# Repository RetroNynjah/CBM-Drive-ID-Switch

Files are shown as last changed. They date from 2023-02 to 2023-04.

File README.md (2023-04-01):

# CBM Drive ID Switch
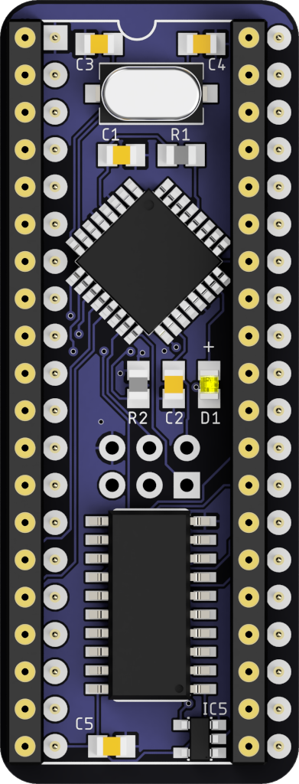
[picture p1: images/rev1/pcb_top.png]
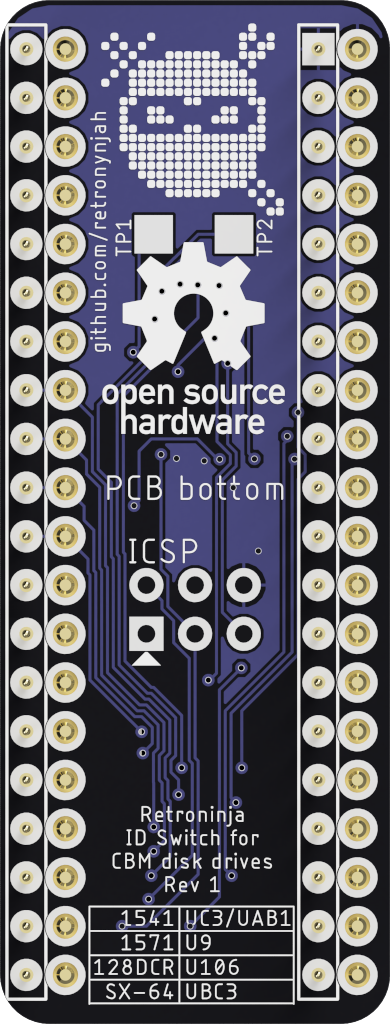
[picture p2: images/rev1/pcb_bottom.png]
   

This is a software controlled device ID switch for Commodore disk drives. It can be installed in any Commodore IEC disk drive but it only makes sense to install it in the drives that lack external DIP switches for ID selection but handy for the 1541 drive and for computers with built-in disk drives such as SX-64, C128D and C128DCR. 

## How it works
There's a microcontroller on the PCB that listens for strings of text on the drive data bus. Once a predefined string of bytes arrives on the bus, it flips the drive ID select pins on the VIA and resets the drive. 
The command that the drive listens for is x@RNDRVID where x is a number representing the drive ID to switch to.
Valid device numbers are 8, 9, 10, 11. In the switch command, these are specified as 8, 9, 0, 1. I.e. 0@RNDRVID is the command for switching to device #10. See the usage section for more information on the command.

## Installation

The installation is quite simple if the VIA chips are socketed. Just remove the correct VIA chip (MOS 6522) indicated in the table below, then install the switch in the socket and install the VIA chip in the switch. There is a notch printed on the top of the switch. This notch should be aligned with the notch on the socket.  
If the VIA is soldered to the PCB you will need to first desolder the VIA and install a socket (unless you want to solder the switch to the PCB which I wouldn't recommend). If you need to remove the VIA chip from the switch, be careful with the compoments on top of the PCB. Don't use any sharp objects to pry the chip out of the headers.

|Model			| VIA			| 
|:---:	|:---:	|
|1541			| UC3 or UAB1	|
|1571 (in 128D) | U9		  	|
|128DCR			| U106			|
|SX-64			| UBC3			|

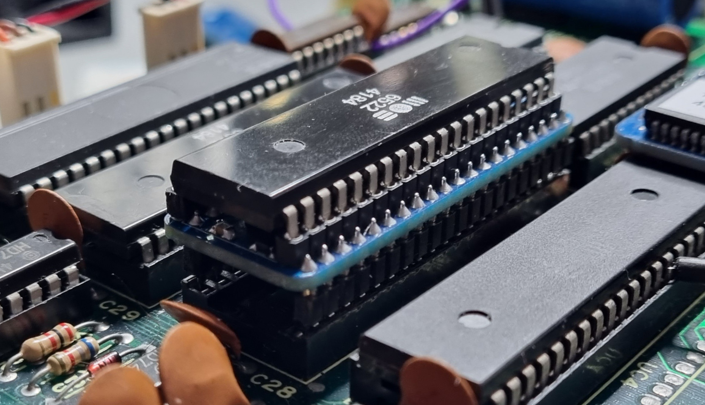
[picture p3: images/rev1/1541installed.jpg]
Switch installed in a CBM 1541

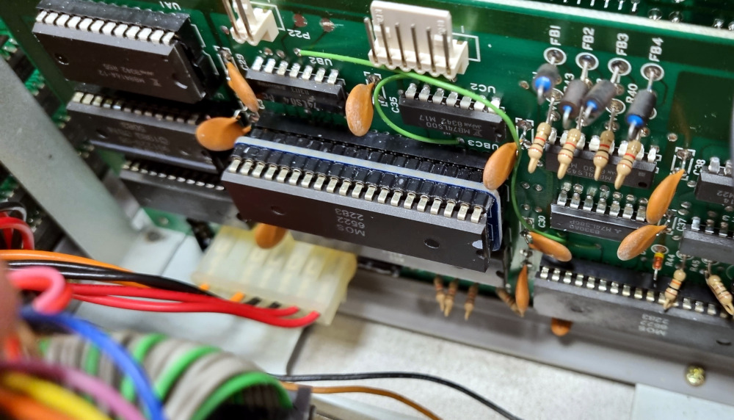
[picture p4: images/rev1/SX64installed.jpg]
Switch installed in an SX-64


## Usage

The device ID can be switched from basic using regular CBM DOS commands or by using DOS wedge commands from JiffyDOS or similar. 
Once the ID has been switched, the ID is saved and the drive will startup with the new ID until the ID is changed again. Resetting or power cycling the drive doesn't affect the saved ID.

In the below examples we switch ID of device #8 to device #9. 

#### From CBM DOS

The easiest command to use to get bytes on the drive bus is the LOAD command but other disk commands can be used too.  
```LOAD "9@RNDRVID",8```  
This generates a file not found error (unless you have a file named 9@RNDRVID ;) ). This error is to be expected and nothing to worry about.  

#### From JiffyDOS
```@"9@RNDRVID",8```  
or activate the drive first using CTRL+D or using @8 and use this command:  
```@9@RNDRVID```

## BOM

|Qty|Identifier |Part						|Comments							|
|---|----------	|---------------------------|-----------------------------------|
| 1 |IC2        |ATmega48A (TQFP32)			|Or compatible						|
| 1 |IC4        |SN74AHCT273NSR (SO20)     	|									|
| 1 |IC5        |SN74AHCT1G04DBVR (SOT23-5)	|									|
| 3 |C1,C2,C5   |100nF 0805    				|Ceramic capacitor					|
| 2 |C3,C4      |30pF 0805					|Ceramic capacitor					|
| 1 |R1         |10kΩ 0805					|									|
| 1 |Y1         |ECS-200-20-3X-TR			|Crystal 20MHz						|
| 2 |			|Female header row 			|20pin 2.54mm (for VIA chip)        |
| 2 |			|Male header row			|20pin 2.54mm (round or flat pins)	|
| 1 |D1			|LED 0805					|Optional							|
| 1 |R2			|560Ω 0805					|Optional							|

You can use any larger pin-compatible ATmega MCU such as ATmega88 or ATmega328.  
All variants seem to work including the not 100% pin-compatible PB version.  
The test points TP1 and TP2 are connected to ATmega pins PC1 and PC2 (Arduino pins A1 and A2) and can possibly be used for debugging or for some external connections.  
The optional LED (D1) and its resistor can also be used for debugging purposes but are difficult to see when VIA is installed so the may as well be left out. 

Installaion in the plastic version of C128D with the 1571 controller board covered by an RF shield requires a low profile switch. Flat stackable headers (Arduino shield headers) soldered from the top side is recommended in this case.  
<img src="images/stackableheader.jpg" alt="Stackable type header" width="400"/>  
Place a socket under the PCB and insert the stackable header pins through the PCB and solder them in place from the top side. The PCB can be removed from socket after soldering a pin on each end. The angle of the pins can then be adjusted before soldering the rest of the pins.
<img src="images/stackableheader2.jpg" alt="Stackable header inserted for soldering" width="600"/>  
When done, cut off the header part so that only the bottom part of the pins are left.  
I haven't found any 20-pin stackable headers but two 10-pin headers on each side works fine.  

Round machined headers add a few millimeters to the height but is fine in C128DCR, SX-64 and 1541 which all have more headroom.  

<img src="images/rev1/build.jpg" alt="Completed switch" width="600"/>

## Parallel version
I also made a version with a header for a parallel cable since parallel connections can be made using the same VIA.  
<img src="images/rev1/par_pcb_top.png" alt="PCB rendering" width="300"/> <img src="images/rev1/par_pcb_bottom.png" alt="PCB rendering" width="300"/>  

It can be used with SpeedDos ROM+Kernal and a userport adapter such as the one designed by Sven Petersen:  
https://github.com/svenpetersen1965/1541-parallel-adapter-SpeedDOS
The header on the Drive ID Switch has the same pinout as the one on Sven Petersen's 1541 adapter.  
With the proper cable, the parallel interface can also be used for nibble transfers with a Zoomfloppy or similar interface.  

<img src="images/rev1/1541parinstalled.jpg" alt="Switch installed in an SX-64" width="600"/>  

The pin-out of the parallel connector is connected to VIA pins according to the below table.

|Header pin |VIA pin    |
|-----------|-----------|
|1          |CA2 (39)   |
|2          |PA0 (2)    |
|3          |PA1 (3)    |
|4          |PA2 (4)    |
|5          |PA3 (5)    |
|6          |PA4 (6)    |
|7          |PA5 (7)    |
|8          |PA6 (8)    |
|9          |PA7 (9)    |
|10         |CB1 (18)   |

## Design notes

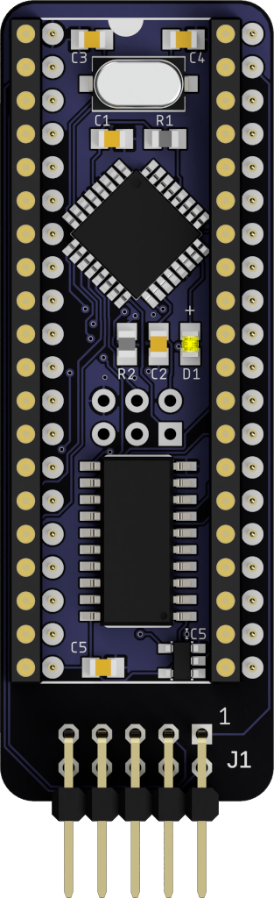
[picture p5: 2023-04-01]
images/rev1/par_pcb_top.png

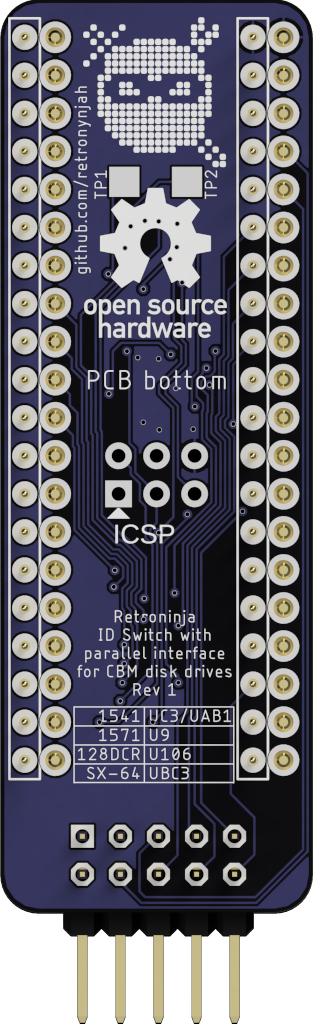
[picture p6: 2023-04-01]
images/rev1/par_pcb_bottom.png

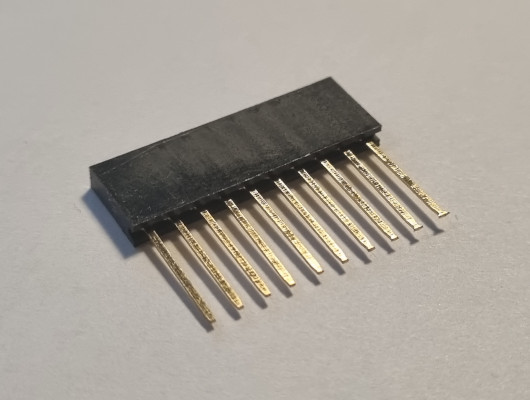
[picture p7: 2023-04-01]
images/stackableheader.jpg

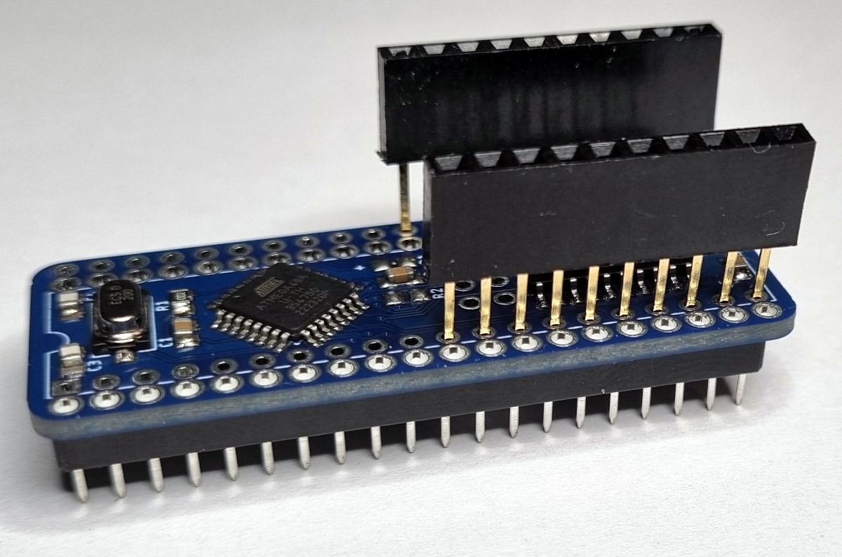
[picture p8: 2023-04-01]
images/stackableheader2.jpg

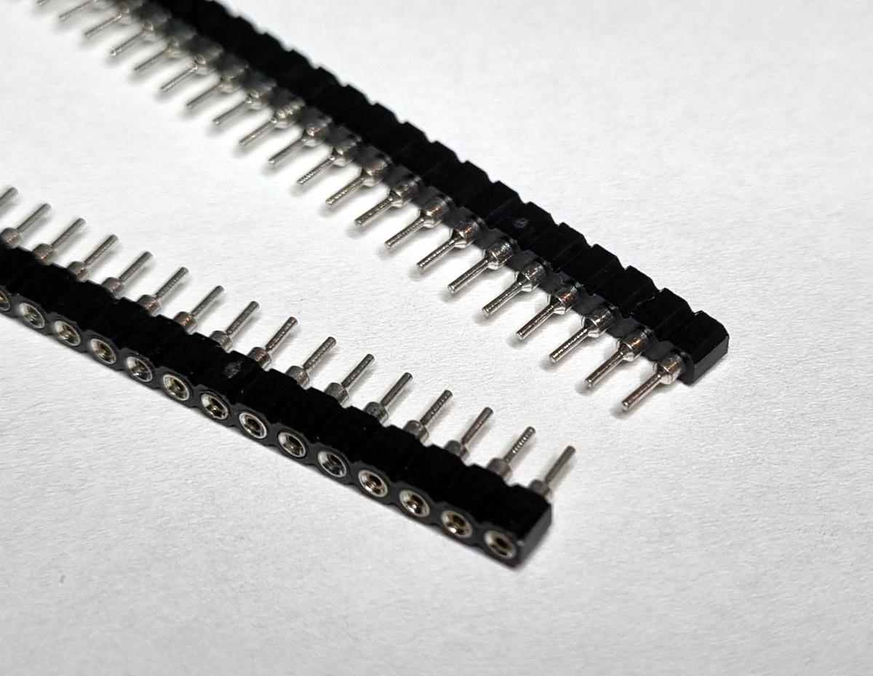
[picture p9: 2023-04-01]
images/femaleheader.jpg

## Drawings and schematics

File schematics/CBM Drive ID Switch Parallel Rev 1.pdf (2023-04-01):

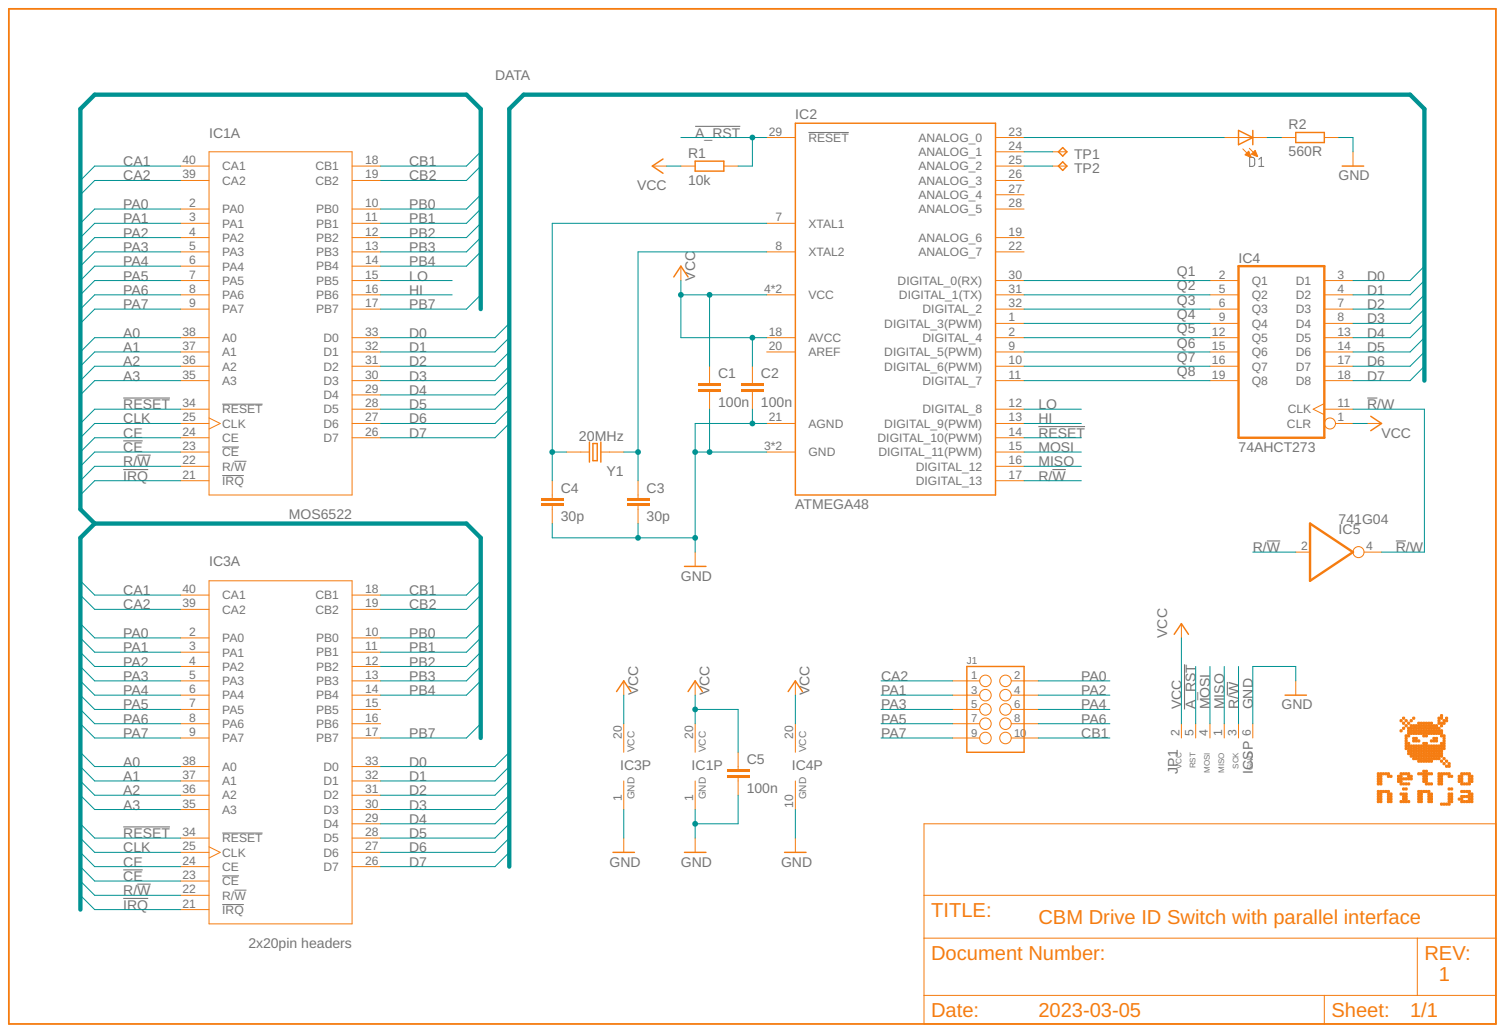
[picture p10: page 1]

SCK RST VCC MOSI GND

CBM Drive ID Switch with parallel interface

Document Number: | REV: 1

Date: 2023-03-05 | Sheet: 1/1

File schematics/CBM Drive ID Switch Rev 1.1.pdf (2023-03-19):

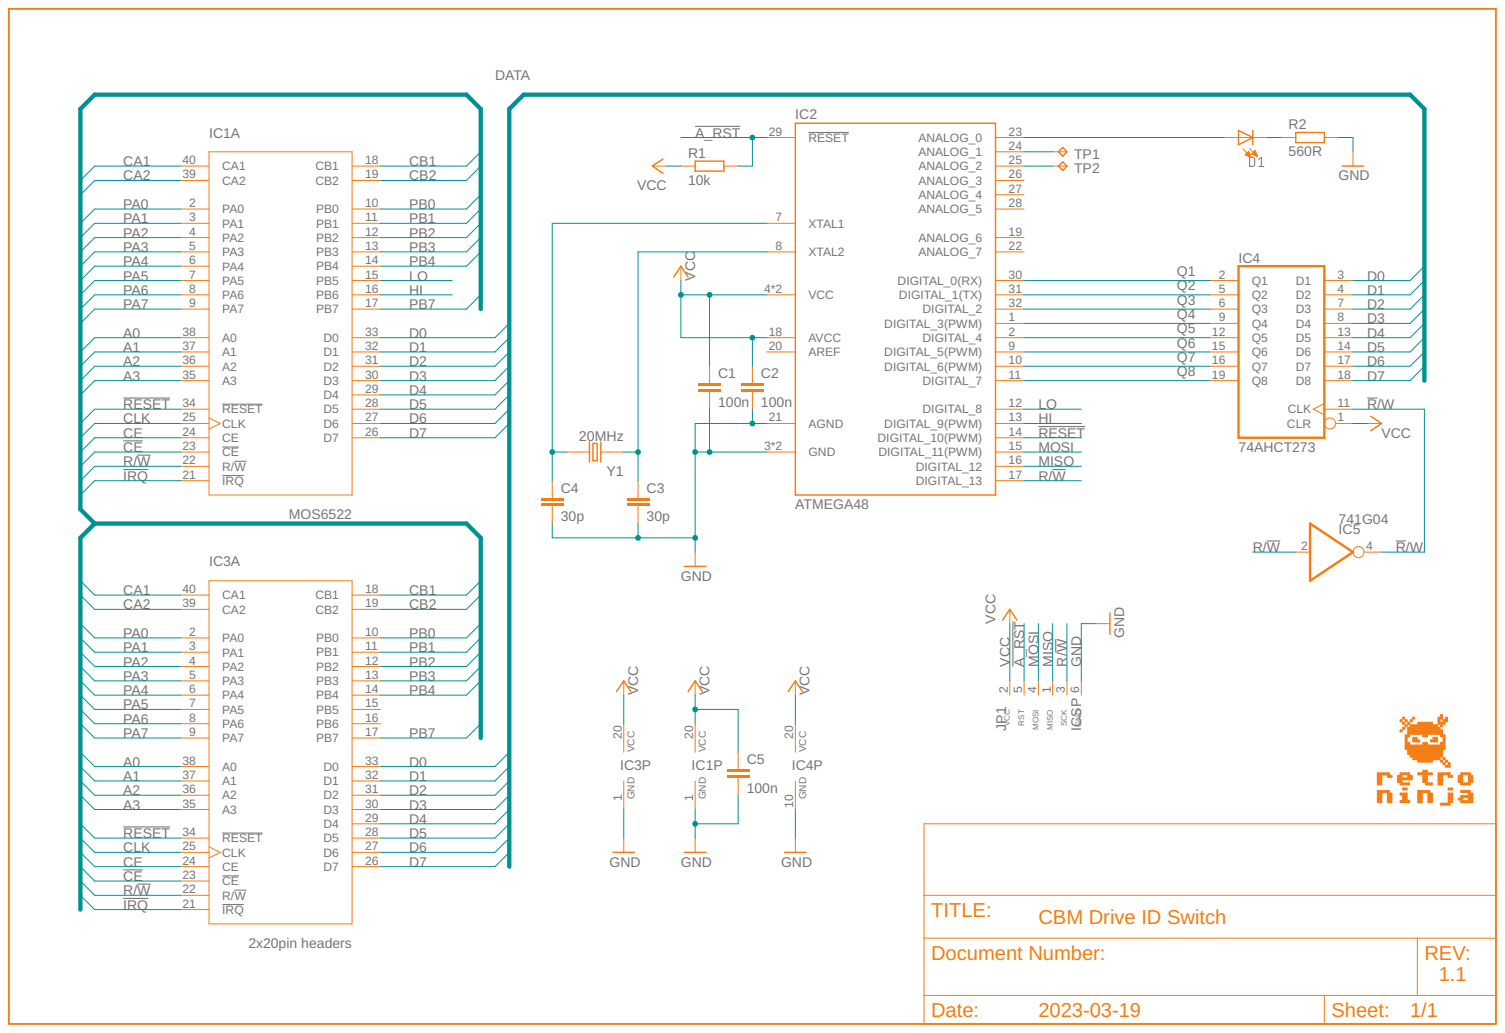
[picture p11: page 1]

SCK RST VCC MOSI GND

CBM Drive ID Switch

Document Number: | REV: 1.1

Date: 2023-03-19 | Sheet: 1/1

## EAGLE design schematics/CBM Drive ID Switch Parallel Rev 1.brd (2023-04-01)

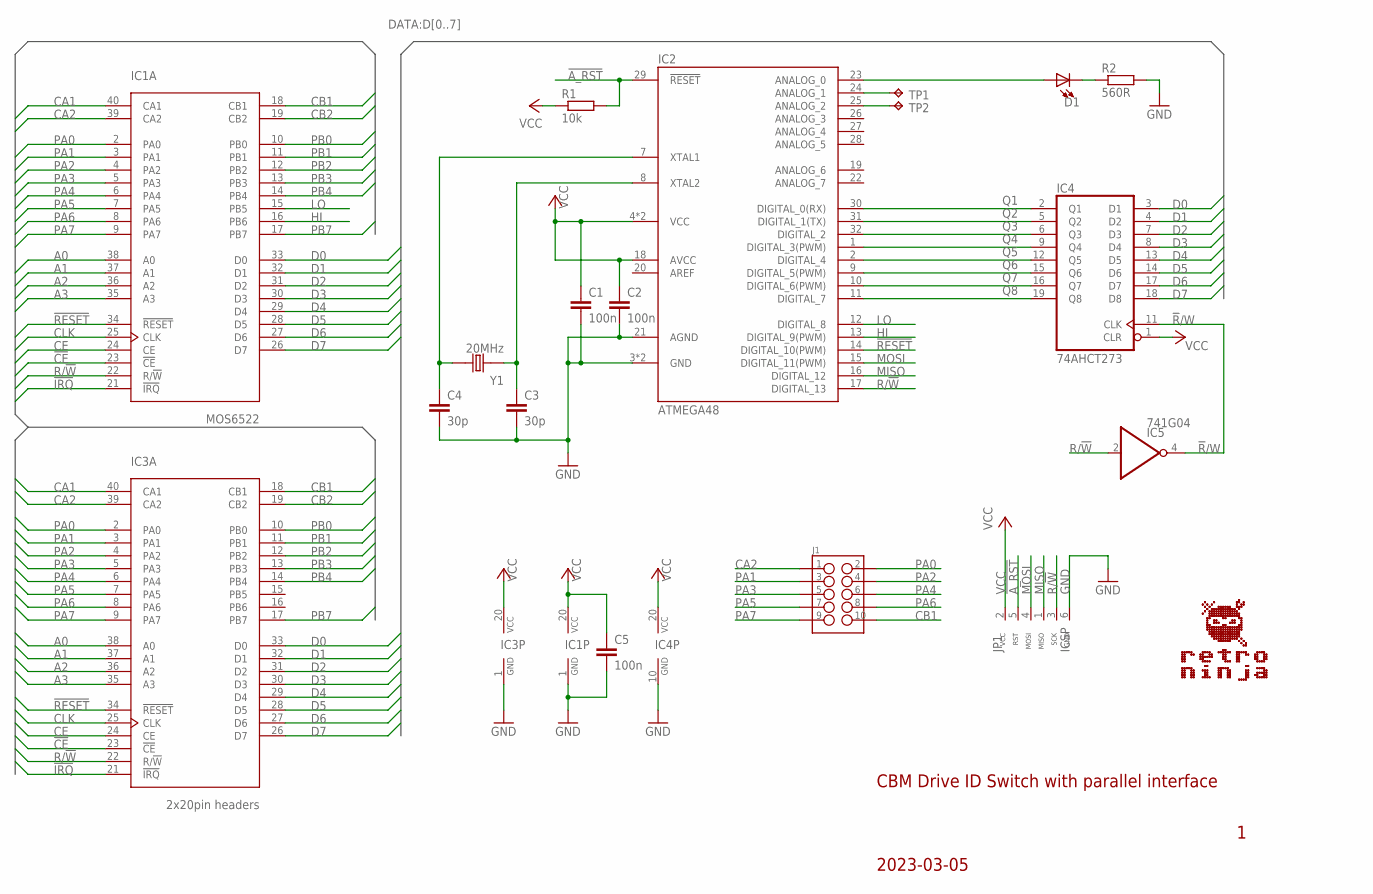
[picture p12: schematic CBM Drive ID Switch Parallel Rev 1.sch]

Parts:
C1, C2, C5: 100n; C0805
C3, C4: 30p; C0805
D1: LED_0805; LED0805
IC1: MOS6522; DIL40-6_HEADERS-F
IC2: ATMEGA48; TQFP-32
IC3: 2x20pin headers; DIL40-6_ROUND_BOTTOMPINS
IC4: 74AHCT273; SO20_NARROW
IC5: 741G04; SOT23-5
J1: HEADER_2X5-WALLED-90; HEADER_2X5_WALLED_RIGHT
JP1: ICSP; HEADER_2X3_ALT
R1: 10k; R0805
R2: 560R; R0805
TP1, TP2: TPTP20SQ; TP20SQ
Y1: 20MHz; CRYSTAL_SMD-2_7X4X2.3

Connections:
!A_RST: IC2.29 (!RESET), JP1.5 (RST), R1.2
!CE: IC1.23 (!CE), IC3.23 (!CE)
!IRQ: IC1.21 (!IRQ), IC3.21 (!IRQ)
!R!/W: IC4.11 (CLK), IC5.4 (O)
!RESET: IC1.34 (!RESET), IC2.14 (DIGITAL_10(PWM)), IC3.34 (!RESET)
A0: IC1.38 (A0), IC3.38 (A0)
A1: IC1.37 (A1), IC3.37 (A1)
A2: IC1.36 (A2), IC3.36 (A2)
A3: IC1.35 (A3), IC3.35 (A3)
CA1: IC1.40 (CA1), IC3.40 (CA1)
CA2: IC1.39 (CA2), IC3.39 (CA2), J1.1
CB1: IC1.18 (CB1), IC3.18 (CB1), J1.10
CB2: IC1.19 (CB2), IC3.19 (CB2)
CE: IC1.24 (CE), IC3.24 (CE)
CLK: IC1.25 (CLK), IC3.25 (CLK)
D0: IC1.33 (D0), IC3.33 (D0), IC4.3 (D1)
D1: IC1.32 (D1), IC3.32 (D1), IC4.4 (D2)
D2: IC1.31 (D2), IC3.31 (D2), IC4.7 (D3)
D3: IC1.30 (D3), IC3.30 (D3), IC4.8 (D4)
D4: IC1.29 (D4), IC3.29 (D4), IC4.13 (D5)
D5: IC1.28 (D5), IC3.28 (D5), IC4.14 (D6)
D6: IC1.27 (D6), IC3.27 (D6), IC4.17 (D7)
D7: IC1.26 (D7), IC3.26 (D7), IC4.18 (D8)
GND: C1.2, C2.2, C3.2, C4.2, C5.2, IC1.1 (GND), IC2.3 (GND), IC2.5 (GND), IC2.21 (AGND), IC3.1 (GND), IC4.10 (GND), IC5.3 (GND), JP1.6 (GND), R2.2
HI: IC1.16 (PB6), IC2.13 (DIGITAL_9(PWM))
LO: IC1.15 (PB5), IC2.12 (DIGITAL_8)
MISO: IC2.16 (DIGITAL_12), JP1.1 (MISO)
MOSI: IC2.15 (DIGITAL_11(PWM)), JP1.4 (MOSI)
unnamed: IC2.24 (ANALOG_1), TP1.TP
unnamed: IC2.25 (ANALOG_2), TP2.TP
unnamed: C3.1, IC2.8 (XTAL2), Y1.1
unnamed: C4.1, IC2.7 (XTAL1), Y1.2
unnamed: D1.A, IC2.23 (ANALOG_0)
unnamed: D1.C, R2.1
PA0: IC1.2 (PA0), IC3.2 (PA0), J1.2
PA1: IC1.3 (PA1), IC3.3 (PA1), J1.3
PA2: IC1.4 (PA2), IC3.4 (PA2), J1.4
PA3: IC1.5 (PA3), IC3.5 (PA3), J1.5
PA4: IC1.6 (PA4), IC3.6 (PA4), J1.6
PA5: IC1.7 (PA5), IC3.7 (PA5), J1.7
PA6: IC1.8 (PA6), IC3.8 (PA6), J1.8
PA7: IC1.9 (PA7), IC3.9 (PA7), J1.9
PB0: IC1.10 (PB0), IC3.10 (PB0)
PB1: IC1.11 (PB1), IC3.11 (PB1)
PB2: IC1.12 (PB2), IC3.12 (PB2)
PB3: IC1.13 (PB3), IC3.13 (PB3)
PB4: IC1.14 (PB4), IC3.14 (PB4)
PB7: IC1.17 (PB7), IC3.17 (PB7)
Q1: IC2.30 (DIGITAL_0(RX)), IC4.2 (Q1)
Q2: IC2.31 (DIGITAL_1(TX)), IC4.5 (Q2)
Q3: IC2.32 (DIGITAL_2), IC4.6 (Q3)
Q4: IC2.1 (DIGITAL_3(PWM)), IC4.9 (Q4)
Q5: IC2.2 (DIGITAL_4), IC4.12 (Q5)
Q6: IC2.9 (DIGITAL_5(PWM)), IC4.15 (Q6)
Q7: IC2.10 (DIGITAL_6(PWM)), IC4.16 (Q7)
Q8: IC2.11 (DIGITAL_7), IC4.19 (Q8)
R/!W: IC1.22 (R/!W), IC2.17 (DIGITAL_13), IC3.22 (R/!W), IC5.2 (I), JP1.3 (SCK)
VCC: C1.1, C2.1, C5.1, IC1.20 (VCC), IC2.4 (VCC), IC2.6 (VCC), IC2.18 (AVCC), IC3.20 (VCC), IC4.1 (CLR), IC4.20 (VCC), IC5.5 (VCC), JP1.2 (VCC), R1.1

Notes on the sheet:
2023-03-05
CBM Drive ID Switch with parallel interface

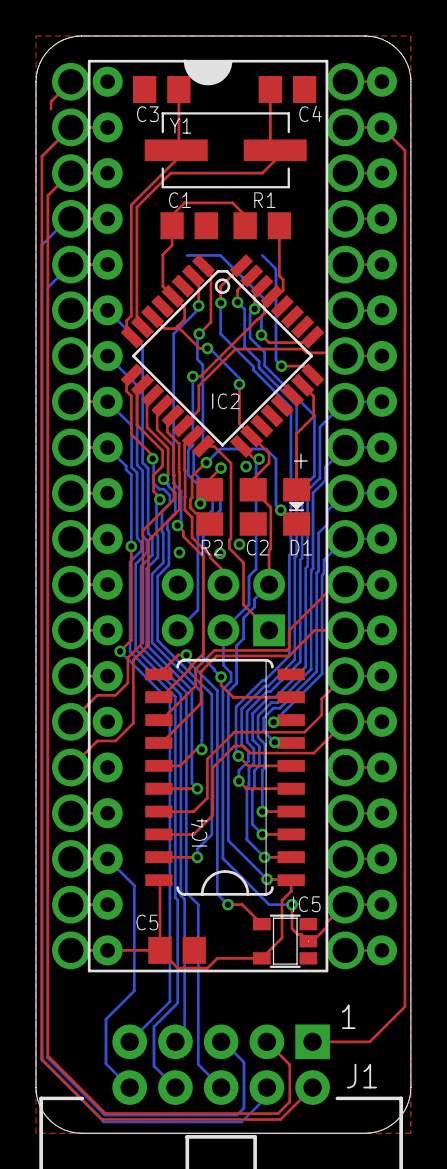
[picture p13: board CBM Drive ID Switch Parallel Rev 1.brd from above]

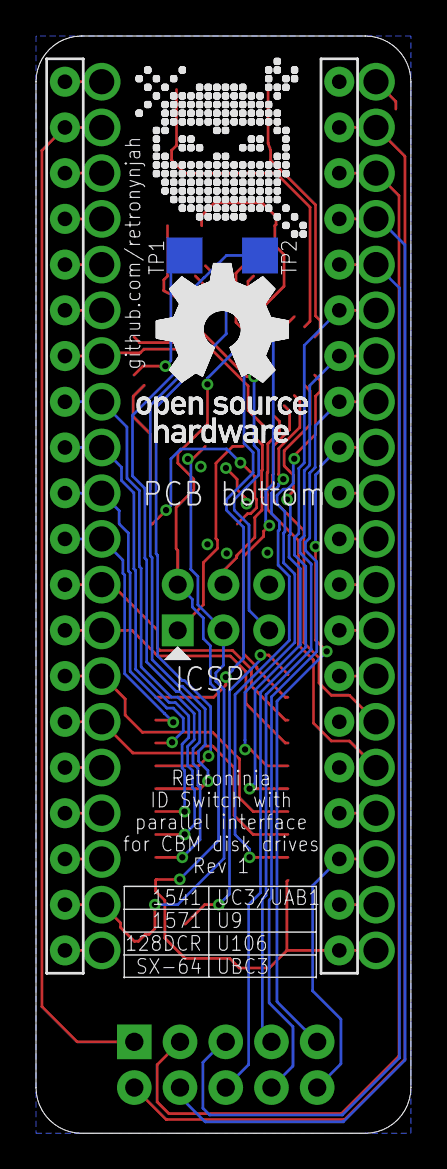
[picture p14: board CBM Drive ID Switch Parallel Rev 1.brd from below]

Board: 2 copper layers, 20.8 x 61.0 mm, 20 parts (5 on the bottom side), 58 nets.

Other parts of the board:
U$1: RETRONINJA_NOTEXT_10MM
U$2: OSHW_10MM

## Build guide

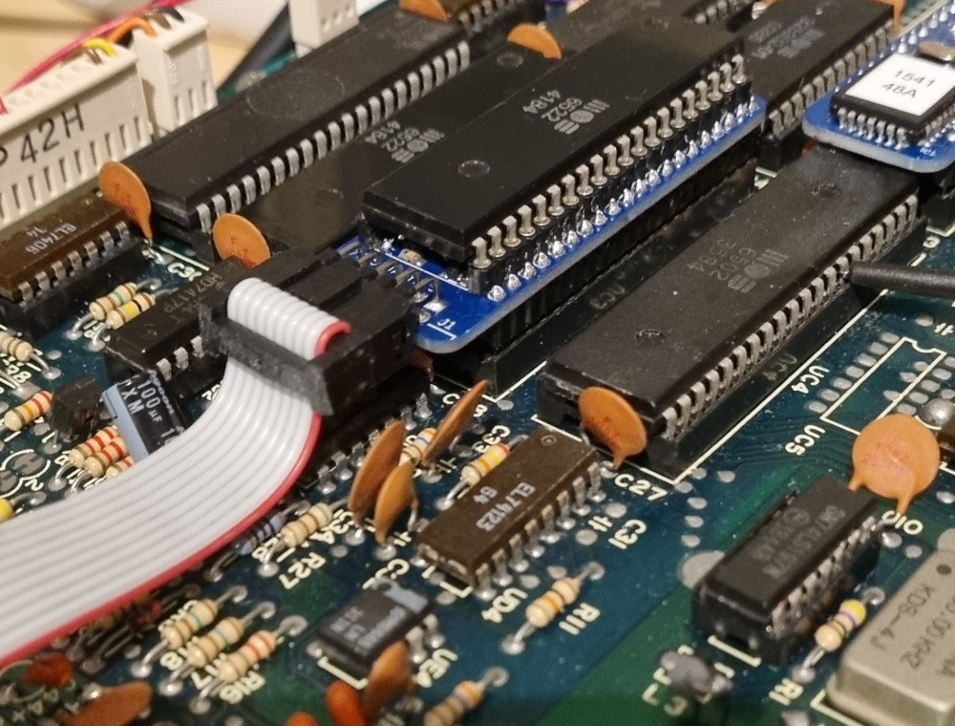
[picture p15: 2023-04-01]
images/rev1/1541parinstalled.jpg

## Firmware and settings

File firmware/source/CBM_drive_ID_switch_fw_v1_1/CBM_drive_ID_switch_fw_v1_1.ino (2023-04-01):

/*
#########################################################################################
#                                                                                       #
#  ID switch sketch for CBM disk drives                                                 #
#  To be used with the Retroninja CBM Drive ID Switch in all CBM IEC drives             #
#                                                                                       #
#  Version 1.1                                                                          #
#  https://github.com/retronynjah                                                       #
#                                                                                       #
#########################################################################################
*/

#include <EEPROM.h>

// searchString is the command that is used for switching ROM.
// It is passed by the 1541-II in reverse order so the variable should be reversed too.
// The command should be preceded by a ROM number between 1 and 4 when used.
// The below reversed searchString in hex ascii is MORNR@ which is specified like this on the C64: 1@RNROM, 2@RNROM and so on.
//byte searchString[] = {0x4D,0x4F,0x52,0x4E,0x52,0x40};
//1@RNDRVID
//DIVRDNR@
byte searchString[] = {0x44,0x49,0x56,0x52,0x44,0x4E,0x52,0x40};

// pin defitions
#define RESETPIN 10
#define CLOCKPIN 13
#define LEDPIN A0
#define LOWBIT 8
#define HIGHBIT 9

int commandLength = sizeof(searchString);
int bytesCorrect = 0;
volatile bool state;
static byte byteCurr;

void pciSetup(byte pin)
{
    *digitalPinToPCMSK(pin) |= bit (digitalPinToPCMSKbit(pin));  // enable pin
    PCIFR  |= bit (digitalPinToPCICRbit(pin)); // clear any outstanding interrupt
    PCICR  |= bit (digitalPinToPCICRbit(pin)); // enable interrupt for the group
}



ISR (PCINT0_vect) // handle pin change interrupt for D8 to D13 here
{    
       // read state of pin 13
       state = PINB & B00100000;
}
 

void cleareeprom(){
  for (int i = 0 ; i < EEPROM.length() ; i++) {
    EEPROM.write(i, 0);
  }
}


void resetdrive(){

  digitalWrite(RESETPIN, LOW);
  pinMode(RESETPIN, OUTPUT);
  delay(50);
  digitalWrite(RESETPIN, HIGH);
  pinMode(RESETPIN, INPUT);

}


void switchid(byte deviceid){
  switch (deviceid){
    case 8:
      // device 8
      digitalWrite(LOWBIT , LOW);
      digitalWrite(HIGHBIT , LOW);
      break;
    case 9:
      // device 9
      digitalWrite(LOWBIT , HIGH);
      digitalWrite(HIGHBIT , LOW);
      break;
    case 0:
      // device 10
      digitalWrite(LOWBIT , LOW);
      digitalWrite(HIGHBIT , HIGH);
      break;
    case 1:
      // device 11
      digitalWrite(LOWBIT , HIGH);
      digitalWrite(HIGHBIT , HIGH);
      break;
    default:
      break;      
  }

  byte savedid = EEPROM.read(0);
  if (savedid != deviceid){
    EEPROM.write(0, deviceid);
  }
  delay(50);
  resetdrive();
  /*
  for (int x = 0; x <= deviceid; x++){
    digitalWrite (LEDPIN, HIGH);
    delay(30);
    digitalWrite (LEDPIN, LOW);
    delay(250);
  }
  delay (200);
  */  
}


void setup() {

  pinMode(LOWBIT, OUTPUT); // device ID low bit (6522 pin 15)
  pinMode(HIGHBIT, OUTPUT); // device ID high bit (6522 pin 16)
  digitalWrite(LOWBIT,HIGH);
  digitalWrite(HIGHBIT,HIGH);
  pinMode(CLOCKPIN, INPUT); // R/!W
  pinMode(RESETPIN, INPUT); // Keep reset pin as input while not performing reset.

  pinMode (LEDPIN, OUTPUT);

  // set data pins as inputs
  DDRD = B00000000;

  // retrieve last used device ID from ATmega EEPROM and switch ID using CIA pin 15/16
  int lastid = EEPROM.read(0);
  if (lastid > 9){
    cleareeprom();
    lastid = 8;
  }
  switchid(lastid);
  
  // enable pin change interrupt on pin D13(PB5) connected to R/W on 6522
  pciSetup(CLOCKPIN); 
  
}


void loop() {
  
  if (state == HIGH){
    byteCurr = PIND;
    state=LOW;
      
    // we don't have full search string yet. check if current byte is what we are looking for
    if (byteCurr == searchString[bytesCorrect]){
      // It is the byte we're waiting for. increase byte counter
      bytesCorrect++;
	    if (bytesCorrect == commandLength){
        // we have our full search string. wait for next byte
		    while(state == LOW){}
    		byteCurr = PIND;
    		// This byte should be the id number
    		// valid numbers are 1-4 (ASCII 49-52)
    		if ((byteCurr >= 48)&&(byteCurr<=57)){
              // rom number within valid range. Switch rom
              switchid(byteCurr - 48);
    		}
    		else if(byteCurr == searchString[0]){
              // it was the first byte in string, starting with new string
              bytesCorrect = 1;
    		}
        else{
          bytesCorrect = 0;
        }
  	  }
    }
    // byte isn't what we are looking for, is it the first byte in the string then?
    else if(byteCurr == searchString[0]){
        // it was the first byte in string, starting with new string
        bytesCorrect = 1;
    }
    else {
      // byte not correct at all. Start over from the beginning
      bytesCorrect = 0;
    }
  }
  
}

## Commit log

2023-02-26 Initial upload
    [CBM Drive ID Switch Rev 1.brd, CBM Drive ID Switch Rev 1.sch]
2023-03-19 Schematics corrected
    Pin names corrected. Informational change only
    [CBM Drive ID Switch Rev 1.1.brd, CBM Drive ID Switch Rev 1.1.sch, CBM Drive ID Switch Rev 1.sch]
2023-04-01 Added parallel adapter, added images, updated firmware (1.1) and README
    Firmware 1.1 adds a short delay before resetting drive to prevent LOAD commnand from hanging some drives.
    [CBM Drive ID Switch Parallel Rev 1.brd, CBM Drive ID Switch Parallel Rev 1.sch, CBM Drive ID Switch Rev 1.1.brd]
2023-04-01 Updated pin header images
